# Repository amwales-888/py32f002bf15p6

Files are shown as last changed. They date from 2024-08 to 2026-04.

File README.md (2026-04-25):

# py32f002bf15p6
Simple breakout board for py32f002bf15p6 tssop20 24MHz 24kB Flash 2kB Ram 18 IOs MCU

- 3.3v LDO powered from 5V USB.
- UART connectivity to USB via ch340 optionally connected to pins PA6/PA7 using jumpers.
- ARM SWD programming interface header.
- All other pins are broken out to headers.
- 1 LED optionally connected to pin PB4 using jumper.
- 1 Button with pulldown optionally connected to pin PB5 using jumper.
- 1 Button connected to RESET pin, pulled high.

<table>
  <tr>
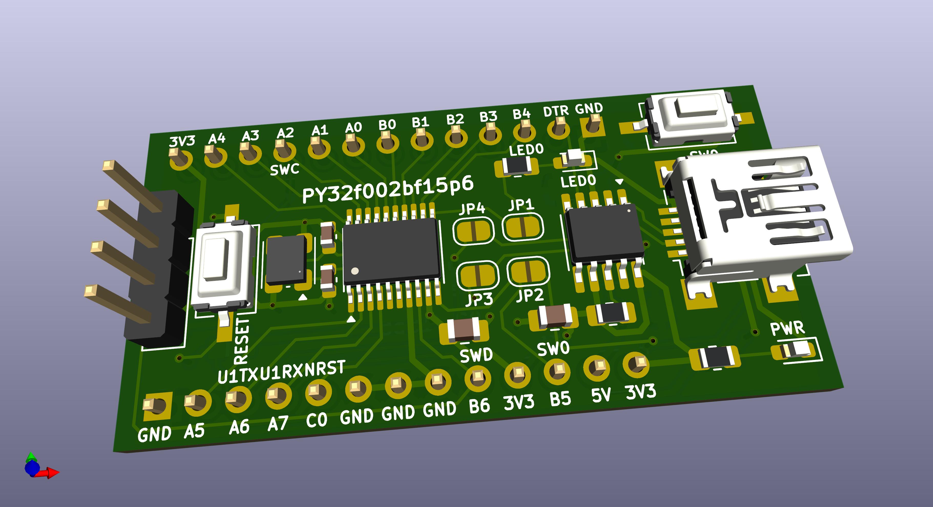
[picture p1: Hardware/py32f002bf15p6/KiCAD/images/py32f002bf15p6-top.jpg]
    <td> </td>
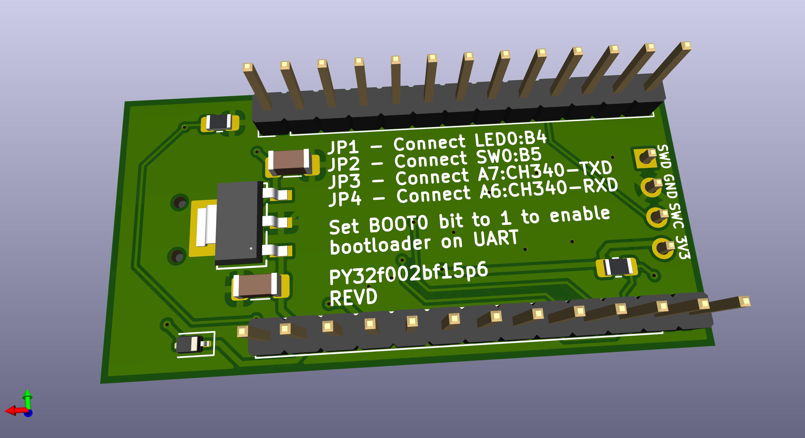
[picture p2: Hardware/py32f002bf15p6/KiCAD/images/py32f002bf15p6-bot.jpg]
    <td> </td>
  </tr>
  <tr>
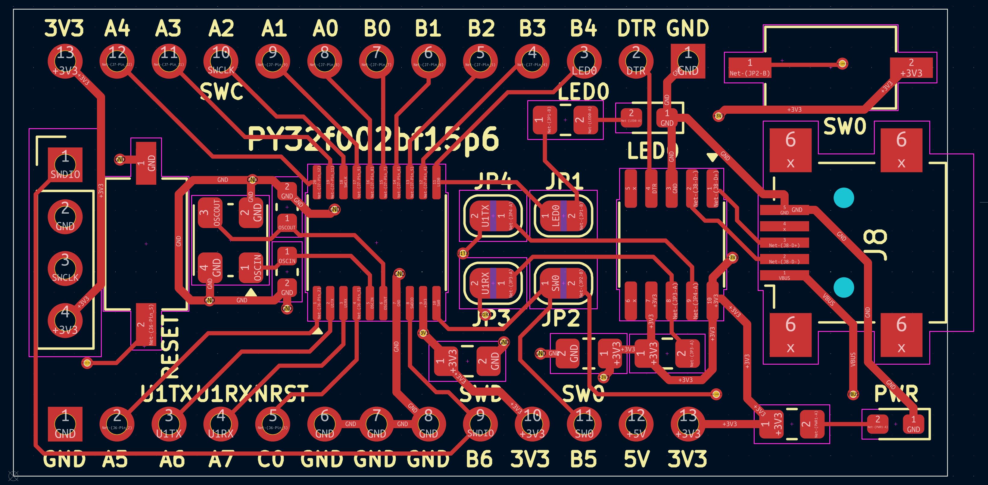
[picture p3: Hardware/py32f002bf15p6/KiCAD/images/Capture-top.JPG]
    <td> </td>
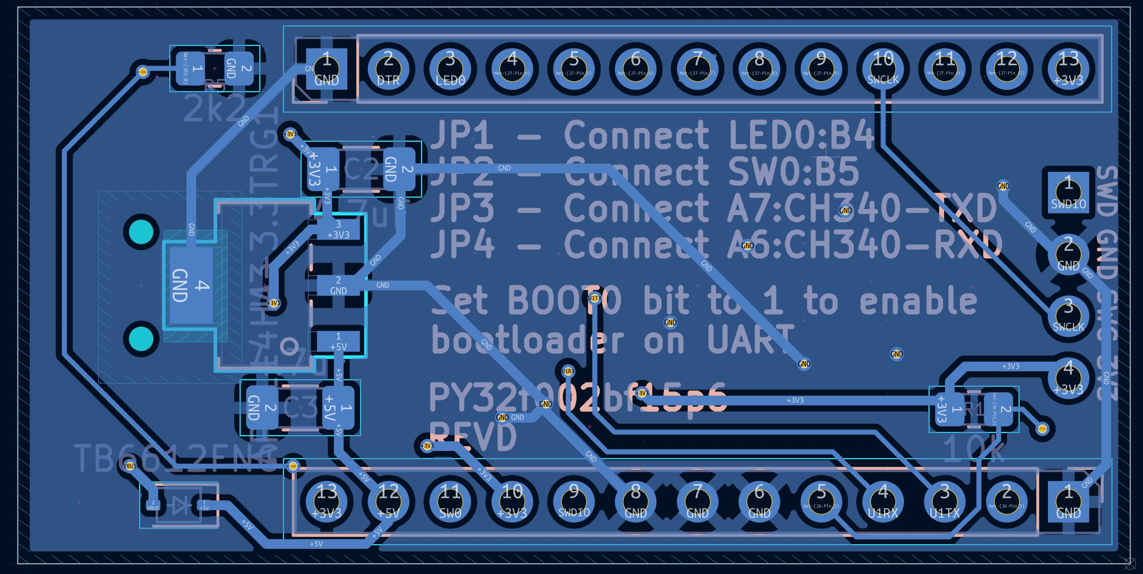
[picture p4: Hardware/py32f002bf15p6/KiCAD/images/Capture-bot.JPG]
    <td> </td>
  </tr>
</table>

Resources

<li>https://www.puyasemi.com/en/py32_series.html</li>
<li>https://www.eevblog.com/forum/microcontrollers/$0-11-py32f002a-m0-24mhz-320kb-actually-324kb-more-peripherals/</li>
<li>https://www.cnblogs.com/milton/p/18168592</li>
<li>https://github.com/IOsetting/py32f0-template/tree/main</li>
<li>https://www.cnblogs.com/milton/p/17111286.html</li>
<li>https://www.cnblogs.com/milton/p/18168592</li>
<li>https://www.lcsc.com/product-detail/C7469098.html</li>

<BR>

Notes - The attached firmware was written for the deprecated board produced with EAGLE, since then I have replaced the 
oscillator with a crystal and may have changed the IO pin for LED0/SW0 review the code before using it. I will update 
it when I have time.

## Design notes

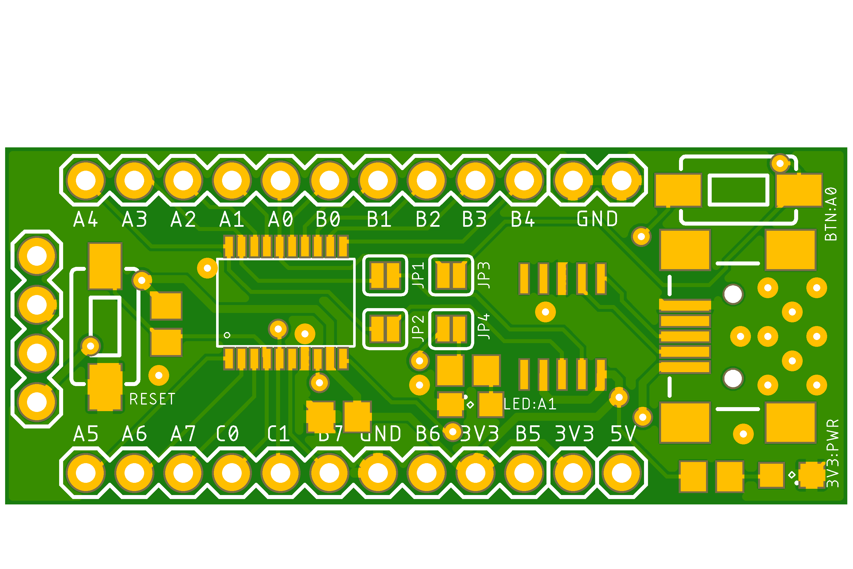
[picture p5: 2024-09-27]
Hardware/py32f002bf15p6/Eagle/images/py32f002bf15p6-Top.png

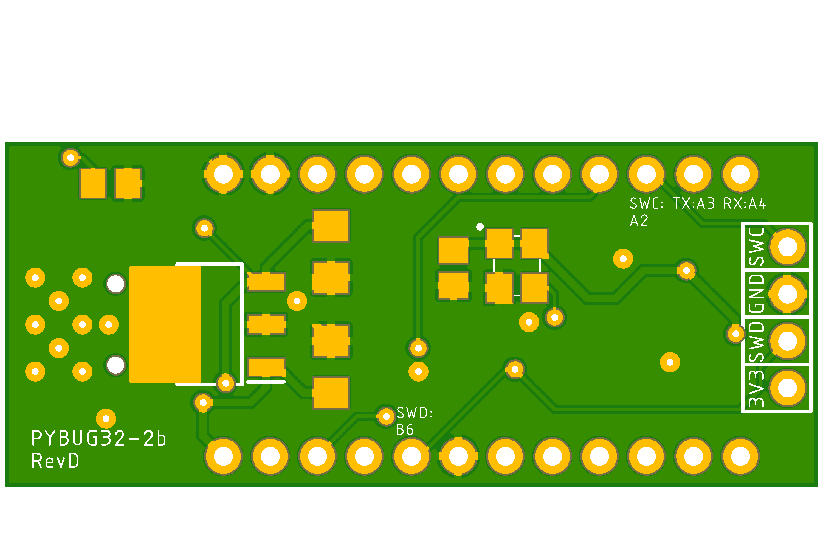
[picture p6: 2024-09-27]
Hardware/py32f002bf15p6/Eagle/images/py32f002bf15p6-Bot.png

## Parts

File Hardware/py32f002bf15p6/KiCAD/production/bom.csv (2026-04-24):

Designator | Footprint | Quantity | Value | LCSC Part #
C1, C5 | 0805 | 2 | 0.1uF
C2, C3 | 1206 | 2 | 4.7uF
C6, C7 | 0603 | 2 | 18pF
D1 | D_SOD-323 | 1 | TB6612FNG
J5 | PinHeader_1x04_P2.54mm_Vertical | 1 | Conn_01x04_Pin
J6, J7 | PinHeader_1x13_P2.54mm_Vertical | 2 | Conn_01x13_Pin
J8 | USB_Mini-B_Lumberg_2486_01_Horizontal | 1 | USB_B_Mini
LED0, PWR1 | 0603 | 2 | LED
R1 | 0805 | 1 | 10k
R2, R5 | 0805 | 2 | 2k2
R3, R4 | 0805 | 2 | 200R
RESET1, SW0 | SW_Tactile_SPST_NO_Straight_CK_PTS636Sx25SMTRLFS | 2 | SW_Push
U1 | SSOP-10-1EP_3.9x4.9mm_P1mm_EP2.1x3.3mm | 1 | CH340K
U3 | SOT-223_DIO | 1 | AP2114HA-3.3TRG1
U4 | TSSOP-20_4.4x6.5mm_P0.65mm | 1 | py32f002bf15p6
Y1 | CDFN-4_2.5x3.2mm_P2.1mm | 1 | 16Mhz Crystal

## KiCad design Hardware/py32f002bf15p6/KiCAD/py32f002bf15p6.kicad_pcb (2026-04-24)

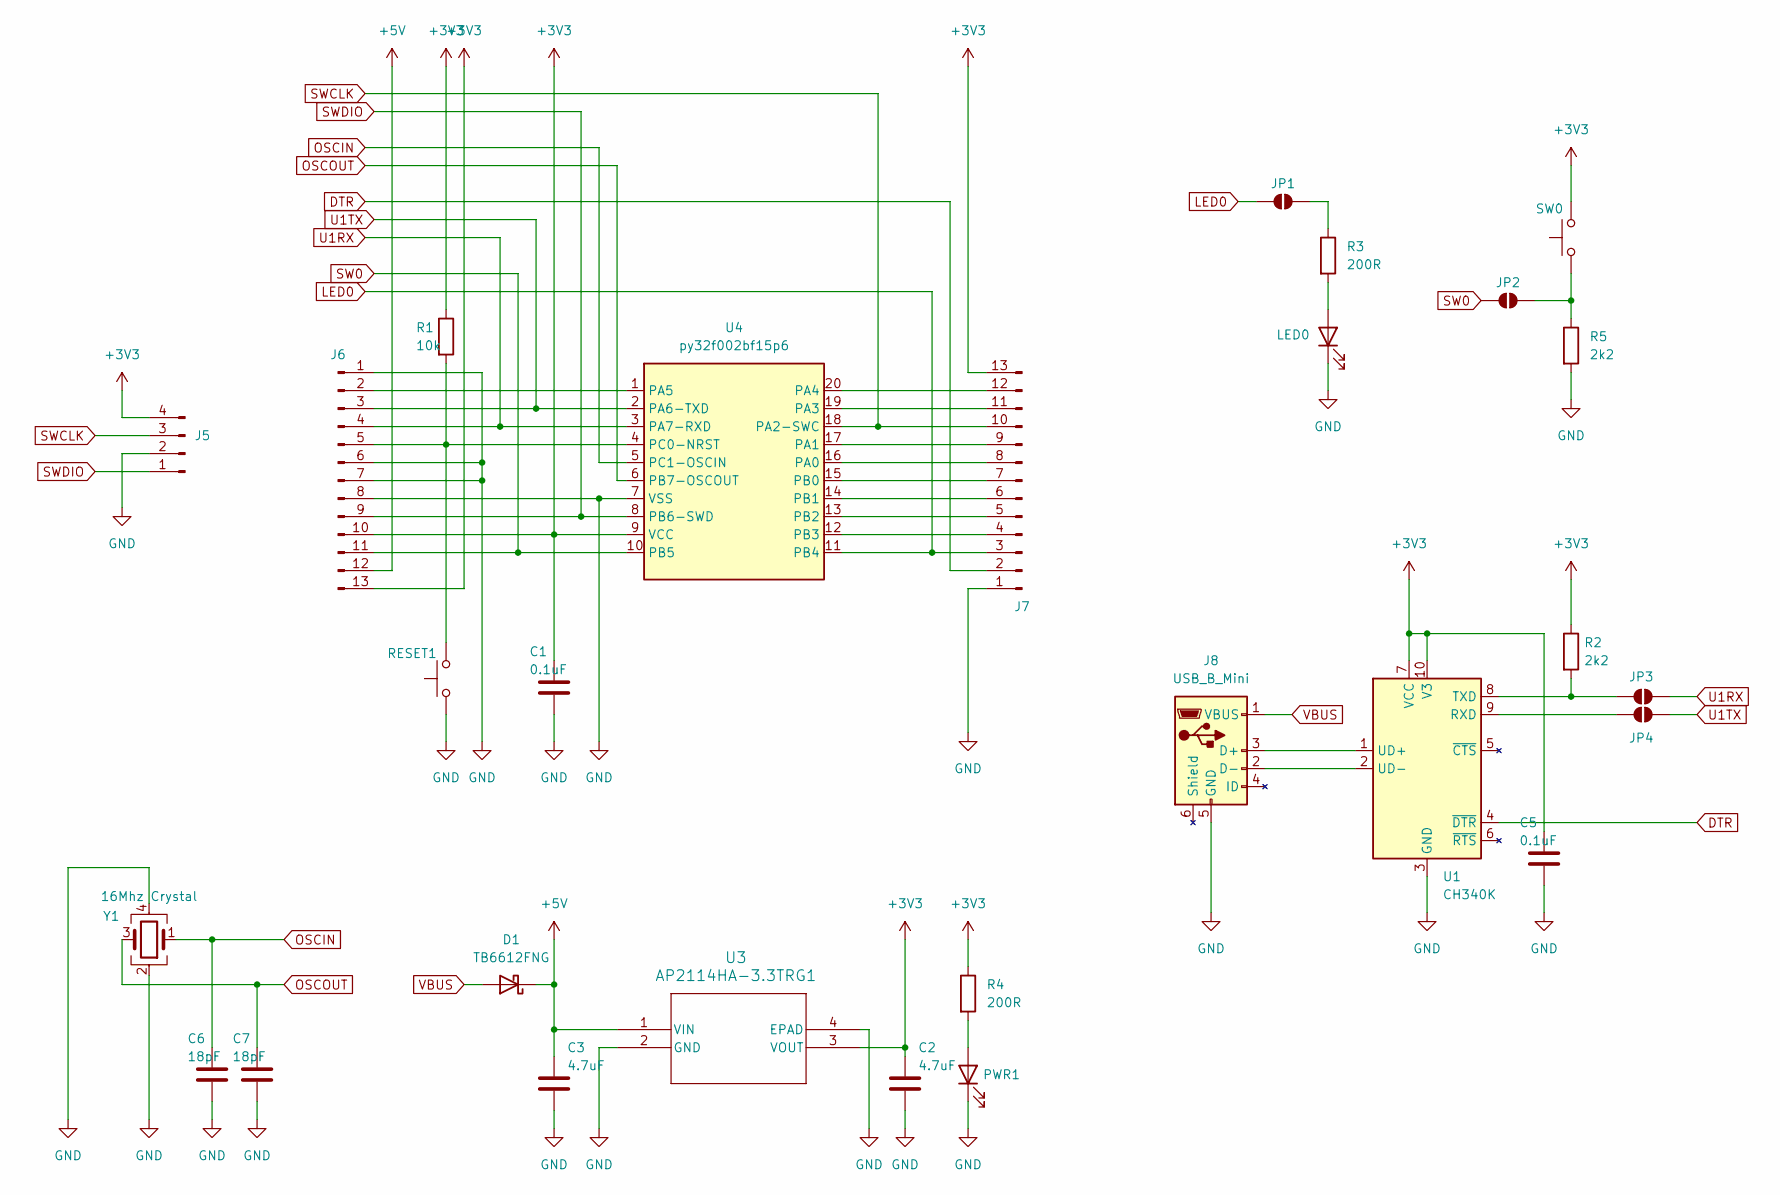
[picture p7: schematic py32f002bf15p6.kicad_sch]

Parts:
C1, C5: 0.1uF; C_0805_2012Metric_Pad1.18x1.45mm_HandSolder
C2, C3: 4.7uF; C_1206_3216Metric_Pad1.33x1.80mm_HandSolder
C6, C7: 18pF; C_0603_1608Metric
D1: TB6612FNG; D_SOD-323; LCSC Part# C88224
J5: Conn_01x04_Pin; PinHeader_1x04_P2.54mm_Vertical
J6, J7: Conn_01x13_Pin; PinHeader_1x13_P2.54mm_Vertical
J8: USB_B_Mini; USB_Mini-B_Lumberg_2486_01_Horizontal; LCSC Part# C105424
JP1, JP2, JP3, JP4: SolderJumper_2_Open; SolderJumper-2_P1.3mm_Open_RoundedPad1.0x1.5mm
LED0: LED; LED_0603_1608Metric_Pad1.05x0.95mm_HandSolder
PWR1: LED; LED_0603_1608Metric_Pad1.05x0.95mm_HandSolder
R1: 10k; R_0805_2012Metric_Pad1.20x1.40mm_HandSolder
R2, R5: 2k2; R_0805_2012Metric_Pad1.20x1.40mm_HandSolder
R3, R4: 200R; R_0805_2012Metric_Pad1.20x1.40mm_HandSolder
RESET1: SW_Push; SW_Tactile_SPST_NO_Straight_CK_PTS636Sx25SMTRLFS
SW0: SW_Push; SW_Tactile_SPST_NO_Straight_CK_PTS636Sx25SMTRLFS
U1: CH340K; SSOP-10-1EP_3.9x4.9mm_P1mm_EP2.1x3.3mm; LCSC Part# C968586
U3: AP2114HA-3.3TRG1; SOT-223_DIO; LCSC Part# C460314
U4: py32f002bf15p6; TSSOP-20_4.4x6.5mm_P0.65mm; LCSC Part# C3018715
Y1: 16Mhz Crystal; CDFN-4_2.5x3.2mm_P2.1mm; LCSC Part# C41383242

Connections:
+3V3: C1.1, C2.1, C5.1, J5.4, J6.10, J6.13, J7.13, R1.1, R2.1, R4.1, SW0.2, U1.7 (VCC), U1.10 (V3), U3.3 (VOUT), U4.9 (VCC)
+5V: C3.1, D1.1 (K), J6.12, U3.1 (VIN)
DTR: J7.2, U1.4 (~DTR)
GND: C1.2, C2.2, C3.2, C5.2, C6.2, C7.2, J5.2, J6.1, J6.6, J6.7, J6.8, J7.1, J8.5 (GND), LED0.1 (K), PWR1.1 (K), R5.2, RESET1.1, U1.3 (GND), U3.2 (GND), U3.4 (EPAD), U4.7 (VSS), Y1.2, Y1.4
LED0: J7.3, JP1.1 (A), U4.11 (PB4)
unnamed: J6.2, U4.1 (PA5)
unnamed: J6.5, R1.2, RESET1.2, U4.4 (PC0-NRST)
unnamed: J7.4, U4.12 (PB3)
unnamed: J7.5, U4.13 (PB2)
unnamed: J7.6, U4.14 (PB1)
unnamed: J7.7, U4.15 (PB0)
unnamed: J7.8, U4.16 (PA0)
unnamed: J7.9, U4.17 (PA1)
unnamed: J7.11, U4.19 (PA3)
unnamed: J7.12, U4.20 (PA4)
unnamed: J8.3 (D+), U1.1 (UD+)
unnamed: J8.2 (D-), U1.2 (UD-)
unnamed: JP1.2 (B), R3.1
unnamed: JP2.2 (B), R5.1, SW0.1
unnamed: JP3.1 (A), R2.2, U1.8 (TXD)
unnamed: JP4.1 (A), U1.9 (RXD)
unnamed: LED0.2 (A), R3.2
unnamed: PWR1.2 (A), R4.2
OSCIN: C6.1, U4.5 (PC1-OSCIN), Y1.1
OSCOUT: C7.1, U4.6 (PB7-OSCOUT), Y1.3
SW0: J6.11, JP2.1 (A), U4.10 (PB5)
SWCLK: J5.3, J7.10, U4.18 (PA2-SWC)
SWDIO: J5.1, J6.9, U4.8 (PB6-SWD)
U1RX: J6.4, JP3.2 (B), U4.3 (PA7-RXD)
U1TX: J6.3, JP4.2 (B), U4.2 (PA6-TXD)
VBUS: D1.2 (A), J8.1 (VBUS)

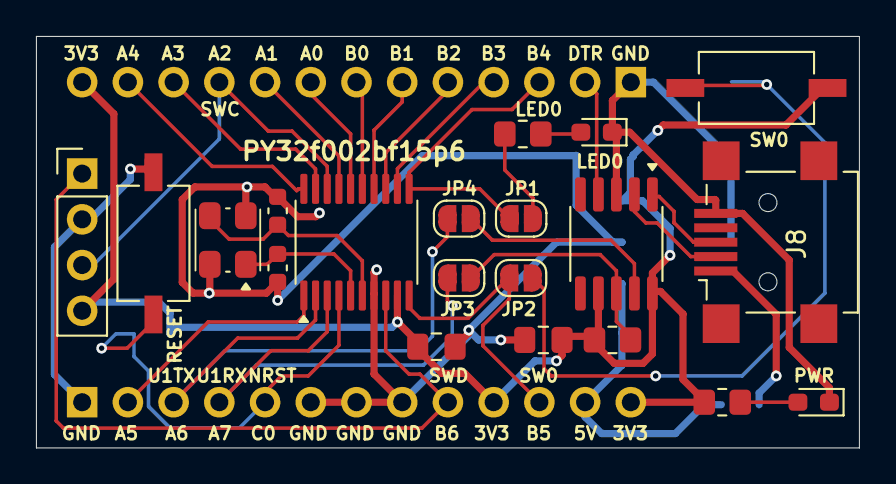
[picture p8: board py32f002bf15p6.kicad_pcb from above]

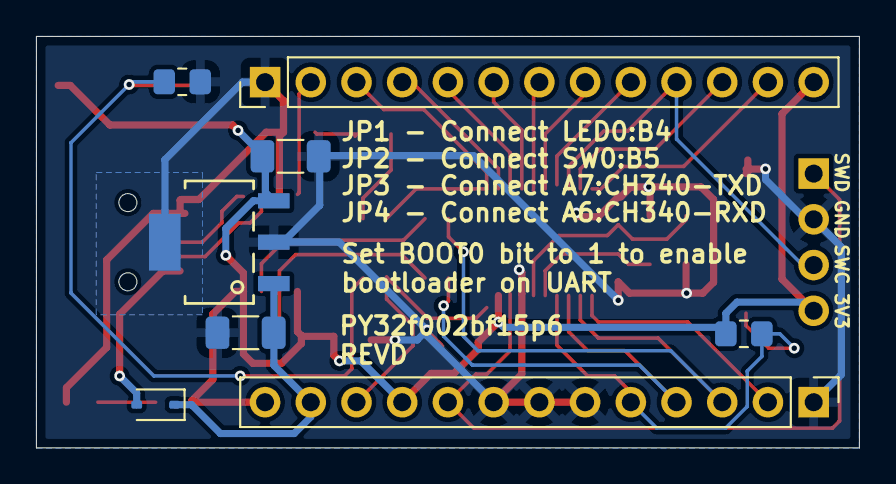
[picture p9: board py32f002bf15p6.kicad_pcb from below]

Board: 2 copper layers, 45.7 x 22.9 mm, 28 parts (8 on the bottom side), 31 nets.

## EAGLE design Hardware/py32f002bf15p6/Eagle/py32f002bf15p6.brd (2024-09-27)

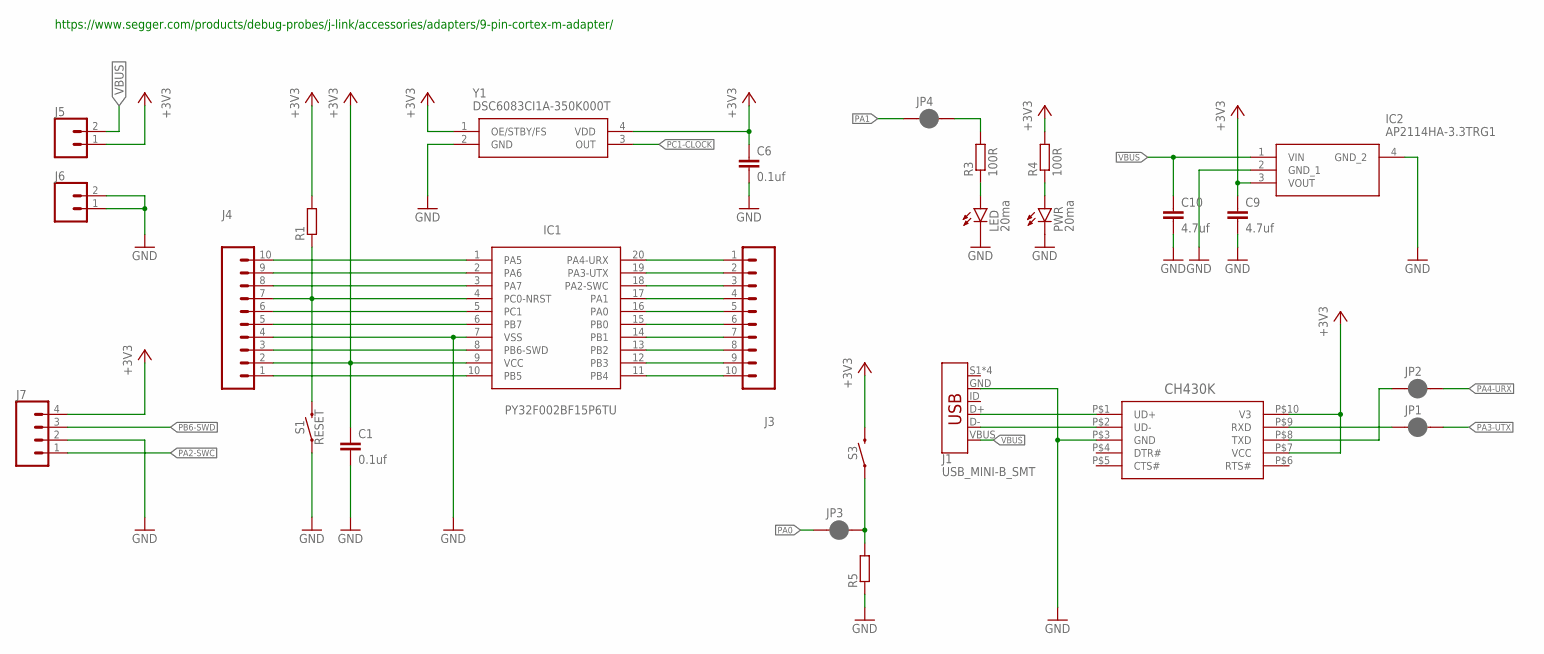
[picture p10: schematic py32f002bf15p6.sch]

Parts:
C1, C6: 0.1uf; C0805
C9, C10: 4.7uf; C1206
IC1: PY32F002BF15P6TU; TSSOP20
IC2: AP2114HA-3.3TRG1; SOT230P700X180-4N
J1: USB_MINI-B_SMT; USB-MINIB
J3, J4: CONN_10"; 1X10
J5, J6: CONN_02; 1X02
J7: CONN_04PTH; 1X04
JP1, JP2, JP3, JP4: JUMPER-SMT_2_NC_PASTE_SILK; SMT-JUMPER_2_NC_PASTE_SILK
LED: 20ma; SML0805
PWR: 20ma; SML0805
R1, R5: R-EU_R0805; R0805
R3, R4: 100R; R0805
S1, S3: RESET; TACTILE_SWITCH_SMD_6.0X3.5MM
U$1: CH430K; ESSOP-10
Y1: DSC6083CI1A-350K000T; DSC6083CI1A350K000T

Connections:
+3V3: C1.1, C6.1, C9.1, IC1.9 (VCC), IC2.3 (VOUT), J4.2, J5.1, J7.4, R1.2, R4.2, S3.2, U$1.P$7 (VCC), U$1.P$10 (V3), Y1.1 (OE/STBY/FS), Y1.4 (VDD)
GND: C1.2, C6.2, C9.2, C10.2, IC1.7 (VSS), IC2.2 (GND_1), IC2.4 (GND_2), J1.GND, J4.4, J6.1, J6.2, J7.2, LED.C, PWR.C, R5.1, S1.1, U$1.P$3 (GND), Y1.2 (GND)
unnamed: JP3.2, R5.2, S3.1
unnamed: LED.A, R3.1
unnamed: JP4.2, R3.2
unnamed: PWR.A, R4.1
PA0: IC1.16 (PA0), J3.5, JP3.1
PA1: IC1.17 (PA1), J3.4, JP4.1
PA2-SWC: IC1.18 (PA2-SWC), J3.3, J7.1
PA3-UTX: IC1.19 (PA3-UTX), J3.2, JP1.2
PA4-URX: IC1.20 (PA4-URX), J3.1, JP2.2
PA5: IC1.1 (PA5), J4.10
PA6: IC1.2 (PA6), J4.9
PA7: IC1.3 (PA7), J4.8
PB0: IC1.15 (PB0), J3.6
PB1: IC1.14 (PB1), J3.7
PB2: IC1.13 (PB2), J3.8
PB3: IC1.12 (PB3), J3.9
PB4: IC1.11 (PB4), J3.10
PB5: IC1.10 (PB5), J4.1
PB6-SWD: IC1.8 (PB6-SWD), J4.3, J7.3
PB7: IC1.6 (PB7), J4.5
PC0-RST: IC1.4 (PC0-NRST), J4.7, R1.1, S1.2
PC1-CLOCK: IC1.5 (PC1), J4.6, Y1.3 (OUT)
RXD: JP1.1, U$1.P$9 (RXD)
TXD: JP2.1, U$1.P$8 (TXD)
USB_N: J1.D-, U$1.P$2 (UD-)
USB_P: J1.D+, U$1.P$1 (UD+)
VBUS: C10.1, IC2.1 (VIN), J1.VBUS, J5.2

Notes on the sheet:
https://www.segger.com/products/debug-probes/j-link/accessories/adapters/9-pin-cortex-m-adapter/

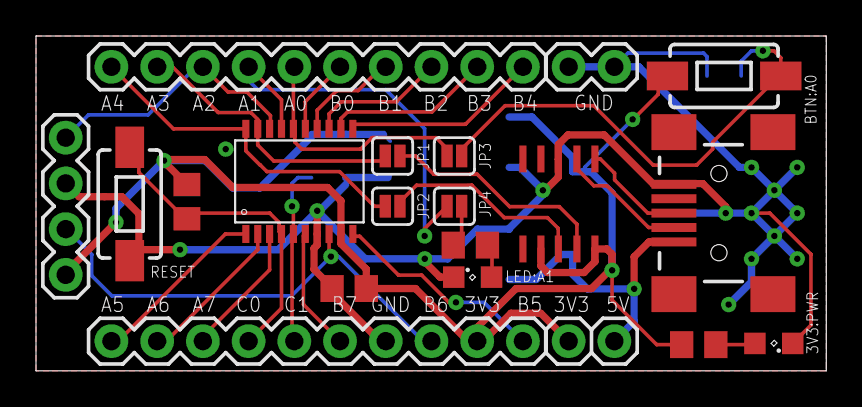
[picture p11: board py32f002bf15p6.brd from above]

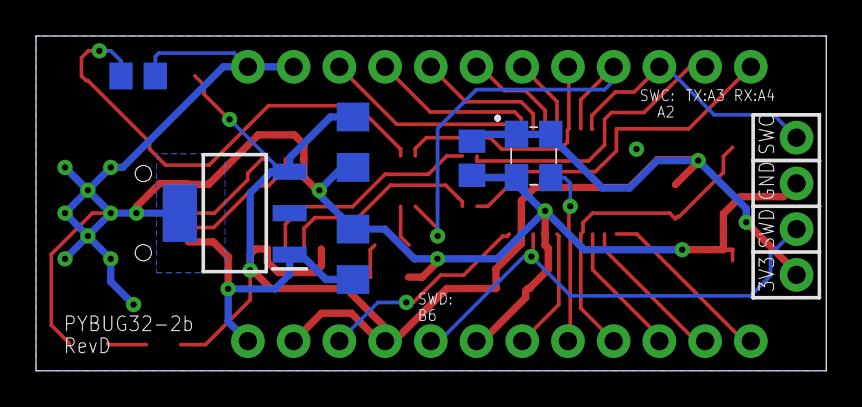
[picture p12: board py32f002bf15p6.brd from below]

Board: 2 copper layers, 43.9 x 18.6 mm, 26 parts (6 on the bottom side), 29 nets.

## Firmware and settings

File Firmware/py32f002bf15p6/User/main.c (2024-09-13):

/**
  ******************************************************************************
  * PY32F002B UART Printf Demo
  * 
  * PA3     -->              USB2TTL-RX
  * PA4     -->              USB2TTL-TX
  */

/* Includes ------------------------------------------------------------------*/
#include "main.h"
#include "py32f002b_bsp_clock.h"
#include "py32f002b_bsp_printf.h"

/* Private function prototypes -----------------------------------------------*/
static void APP_GpioConfig(void);

/**
  * @brief  Main program.
  * @retval int
  */
int main(void)
{
  uint8_t count = 0;
		
  BSP_RCC_HSI_48MConfig();

  /* Configure PA1 pin in output push-pull mode to drive external LEDs */
  APP_GpioConfig();

  /* LED off*/
  LL_GPIO_SetOutputPin(GPIOA, LL_GPIO_PIN_1);
	
  BSP_USART_Config(9600);
  printf("PY32F002B LED Blink and UART Printf Demo\r\nClock: %u\r\n", SystemCoreClock);

  while (1)
  {
    printf("print count: %d\r\n", count++);
    LL_mDelay(1000);
		LL_GPIO_TogglePin(GPIOA, LL_GPIO_PIN_1);
  }
}

void APP_ErrorHandler(void)
{
  /* Infinite loop */
  while (1);
}

/**
  * @brief  GPIO configuration program
  * @param  None
  * @retval None
  */
static void APP_GpioConfig(void)
{
  /* Enable GPIOA clock */
  LL_IOP_GRP1_EnableClock(LL_IOP_GRP1_PERIPH_GPIOA);

  /* Configure PA1 in output mode */
  LL_GPIO_SetPinMode(GPIOA, LL_GPIO_PIN_1, LL_GPIO_MODE_OUTPUT);
  /* Default output type (after reset) is push-pull */
  /* LL_GPIO_SetPinOutputType(GPIOA, LL_GPIO_PIN_1, LL_GPIO_OUTPUT_PUSHPULL); */
  /* Configure GPIO speed in low speed */
  /* LL_GPIO_SetPinSpeed(GPIOA, LL_GPIO_PIN_1, LL_GPIO_SPEED_FREQ_LOW); */
  /* Default (after reset) is no pull */
  /* LL_GPIO_SetPinPull(GPIOA, LL_GPIO_PIN_1, LL_GPIO_PULL_NO); */
}



#ifdef  USE_FULL_ASSERT
/**
  * @brief  Reports the name of the source file and the source line number
  *         where the assert_param error has occurred.
  * @param  file：Pointer to the source file name
  * @param  line：assert_param error line source number
  * @retval None
  */
void assert_failed(uint8_t *file, uint32_t line)
{
  /* User can add His own implementation to report the file name and line number,
     tex: printf("Wrong parameters value: file %s on line %d\r\n", file, line) */
  /* Infinite loop */
  while (1);
}
#endif /* USE_FULL_ASSERT */

/************************ (C) COPYRIGHT Puya *****END OF FILE******************/

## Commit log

2024-08-14 Initial Checkin
    [py32f002b.brd, py32f002b.sch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]
2024-08-31 Final Draft
    [py32f002b.brd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]
2024-09-03 Looks likes I screwed up UART TX/RX pins
    Looks likes I screwed up UART TX/RX pins - im blaming submitting the board after returning from holiday before rechecking
    [py32f002c.brd, py32f002c.sch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]
2024-09-10 Ensure button is pulled down
    Ensure button is pulled down
    [py32f002c.brd, py32f002c.sch]
2024-09-13 Added simple demo that toggles LED and send output to serial at 9600,8,n,1 through attached USB/Serial interface chip
2024-09-13 Generate final gerbers and rename directories to match chip name
    [py32f002b.sch, py32f002bf15p6.brd, py32f002bf15p6.sch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]
2024-09-13 remove old file
    [py32f002c.brd]
2024-09-20 Replaced 4.7uf 0805 caps for larger 1206 parts
    [py32f002bf15p6.brd, py32f002bf15p6.sch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]
2024-09-27 Updated silkscreen, removed reset header pin
    [py32f002bf15p6.brd, py32f002bf15p6.sch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]
2026-04-24 Reformat Directory Structure and Add KiCAD version
    Reformat Directory Structure and Add KiCAD version
    [bom.csv, designators.csv, positions.csv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]
2026-04-24 Update README with corrected pin connections and images
2026-04-24 Change silkscreen and update gerbers
    [py32f002bf15p6.kicad_pcb]
2026-04-24 Deprecated old eagle layout
    Deprecated old eagle layout
    [py32f002bf15p6.brd, py32f002bf15p6.sch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]

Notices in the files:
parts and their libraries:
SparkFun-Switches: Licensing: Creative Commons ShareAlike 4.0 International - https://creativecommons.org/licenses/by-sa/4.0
